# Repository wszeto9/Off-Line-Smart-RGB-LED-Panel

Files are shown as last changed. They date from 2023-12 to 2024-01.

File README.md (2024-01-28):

# Off-Line Smart RGB LED Panel
A constant current driver made to to drive 100W RGB COB LEDs straight from mains power

[Interactive BOM](https://htmlpreview.github.io/?https://github.com/wszeto9/Off-Line-Smart-RGBCCT-LED-Panel/blob/main/ibom.html)

## Testing and Validation

This is probably the most complicated board I've made so far! This isn't because it has more circuits or anything, but rather because it's powered off AC mains. I can't just plug it in and hope that it works. There's an insignificant chance it doesn't, and who knows what will happen to the circuit if a component doesn't work as expected. It goes without saying, don't try this at home! It's taken me years to feel okay designing a system like this, and it isn't a project to build on a whim. Nevertheless, let's look into the bringup process. 

### 24VDC Buck

One of the easiest things to test is the 24V Buck converter. Solder it up, and stick +50VDC (0.1A max) between +HV and -HV. It's safe enough for me to feel comfortable testing it alone. Flip the power switch, and the conviniently placed LED indicator turns on, suggesting that the power rail works. Sticking a multimeter on the power rail shows... ***25.5V***? Interesting. I wonder if it's because there's no load on it. I'll have to look at it again once I get some load put together. For now, it's fine. The 3.3V regulator doesn't care as long as it's below 28V, and the LED drivers are okay with up to a few hundred volts. The LNK3206 IC the design is based on also has a soft-start feature, and that seems to work great. Rise time seems to be ~ 16 ms, no overshoots or anything. Cool! 

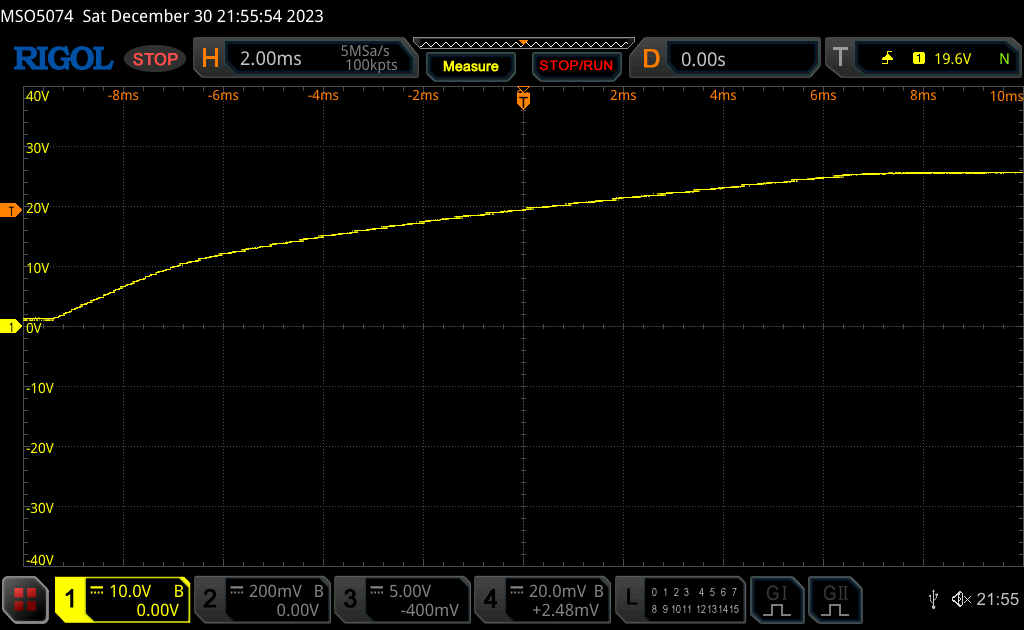
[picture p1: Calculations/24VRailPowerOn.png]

*Soft-start of 24V rail. +HV = 60V DC*

### Bulk Capacitor Discharge Testing

Before I even consider plugging this into the wall, I need to ensure that the bulk capacitors are able to drain in a reasonable time after being unplugged. Bulk capacitors without bleed resistors are one of the scariest things to see. There's no telling whether it's at 400V or 0V simply by looking, and one slip up during measurement would be very dangerous. In this test, I'll inject +60VDC between +HV and -HV. Then I'll measure the voltage across C2. +60VDC is high enough that I can extrapolate discharge rate to +169VDC, while also being low enough that I'd be okay starting with it. 

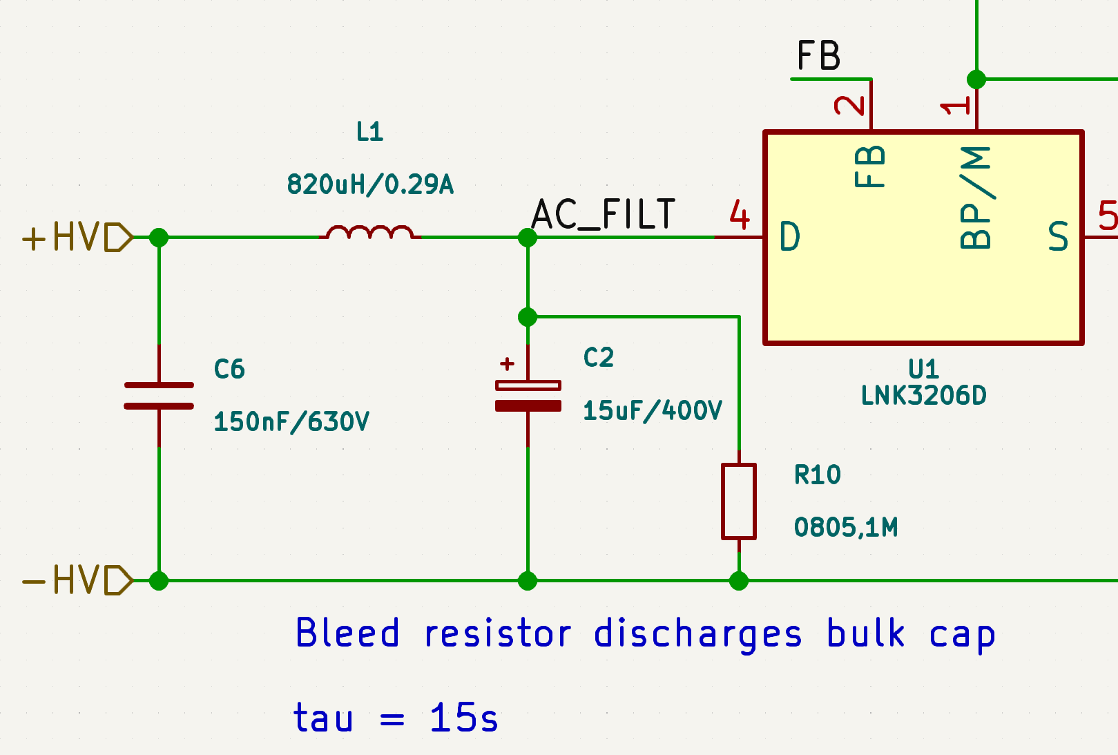
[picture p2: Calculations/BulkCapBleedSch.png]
Bulk Capacitor Discharge Schematic

*Schematic of Bleed Circuit, Rev A02*

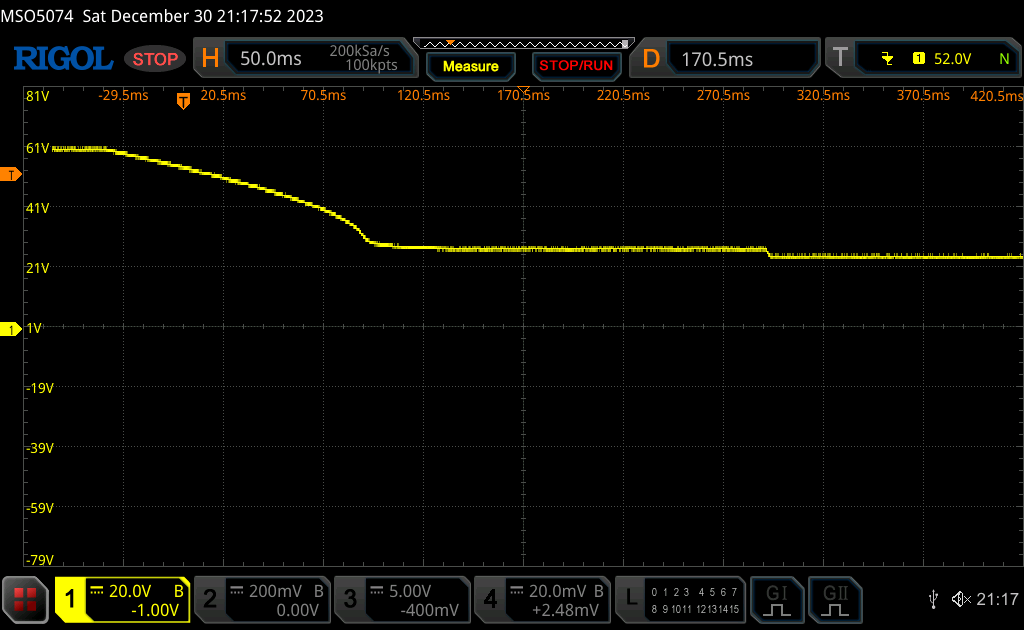
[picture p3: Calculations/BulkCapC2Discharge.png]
Bulk Capacitor Discharge Schematic

*Voltage across C2 after +HV is turned off. Initial discharge rate seems to be approximately 20V/100ms, or 200V/s*

Looking at the discharge rate, it seems to be much higher than expected. The calculations show a 15 second time-constant from a 1M/15.5uF system. The measured time constant is much less than 1 second. This might be since the Buck converter is attached to the circuit, which has ~ 10k of load at 24V. Assuming 100% efficiency, that would equate to ~ 24k of load at 60V, and it's also a psudo-constant power load since the buck converter wants to keep the output at 24V. With a 24k / 15.5uF system, that gets a tau of 0.36 seconds, fairly close to what's observed. The constant power load also explain why the discharge rate seems to accelerate when the capacitor voltage gets closer to 25V.

### LED Current Regulation Testing, 62VDC

Once the +24V Buck was validated, the LED driver can be validated next. +HV is set to +62VDC since that's the highest 2x 30V power supplies can deliver. A 12V LED strip was used to be a load for testing. The LED strip drew 1A at 12V for a total of 12W of power draw. The power supplies were set to 0.2A max in order to ensure that in the event that the LED driver did not work, the LEDs would not be supplied past their rated power. 

When powered up, the LEDs do not turn on until a 3.3V PWM signal was applied. Once the PWM signal was applied, the LED strip did not shine at full brightness. This is likely because the LD configuration only allows for full power draw when +HV is at 169VDC. Since +HV is +62VDC, the LEDs are likely at roughly 1/3 the maximum current draw. 

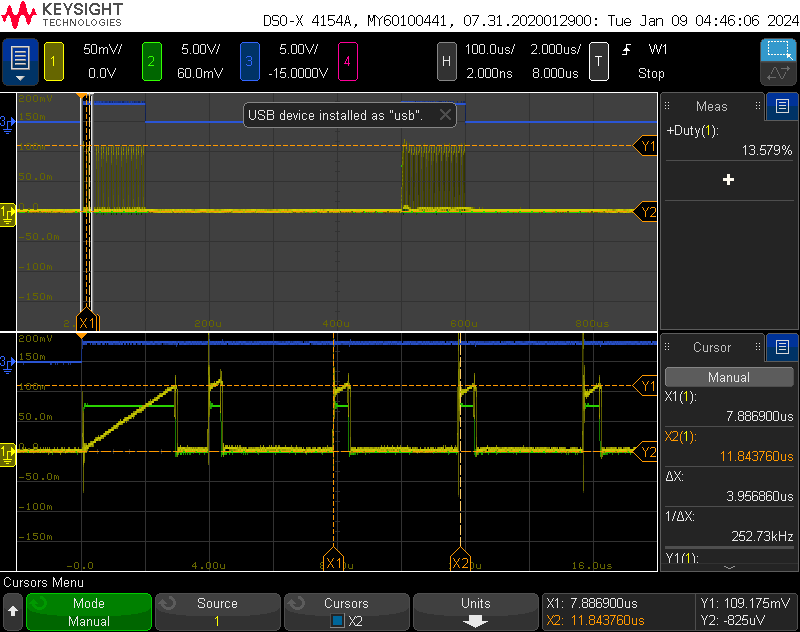
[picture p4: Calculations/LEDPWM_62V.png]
LED PWM testing, 62VDC +HV, 20% PWM


Scope capture of LED current regulation, Rev A02. +HV = 62V, PWM = 20% Duty Cycle, 3.3V logic. Blue = PWM, Green = GATE, Yellow = Isense. 0.1V on Isense is 0.33A.

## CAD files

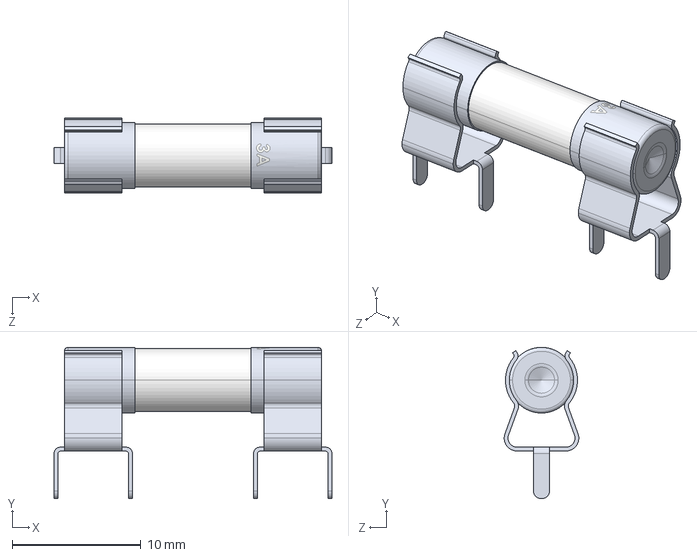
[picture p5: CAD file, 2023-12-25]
3D Models/Fuse Holder.STEP
21.6 x 11.8 x 5.80 mm
Fuse Clip x 2
3A Fuse

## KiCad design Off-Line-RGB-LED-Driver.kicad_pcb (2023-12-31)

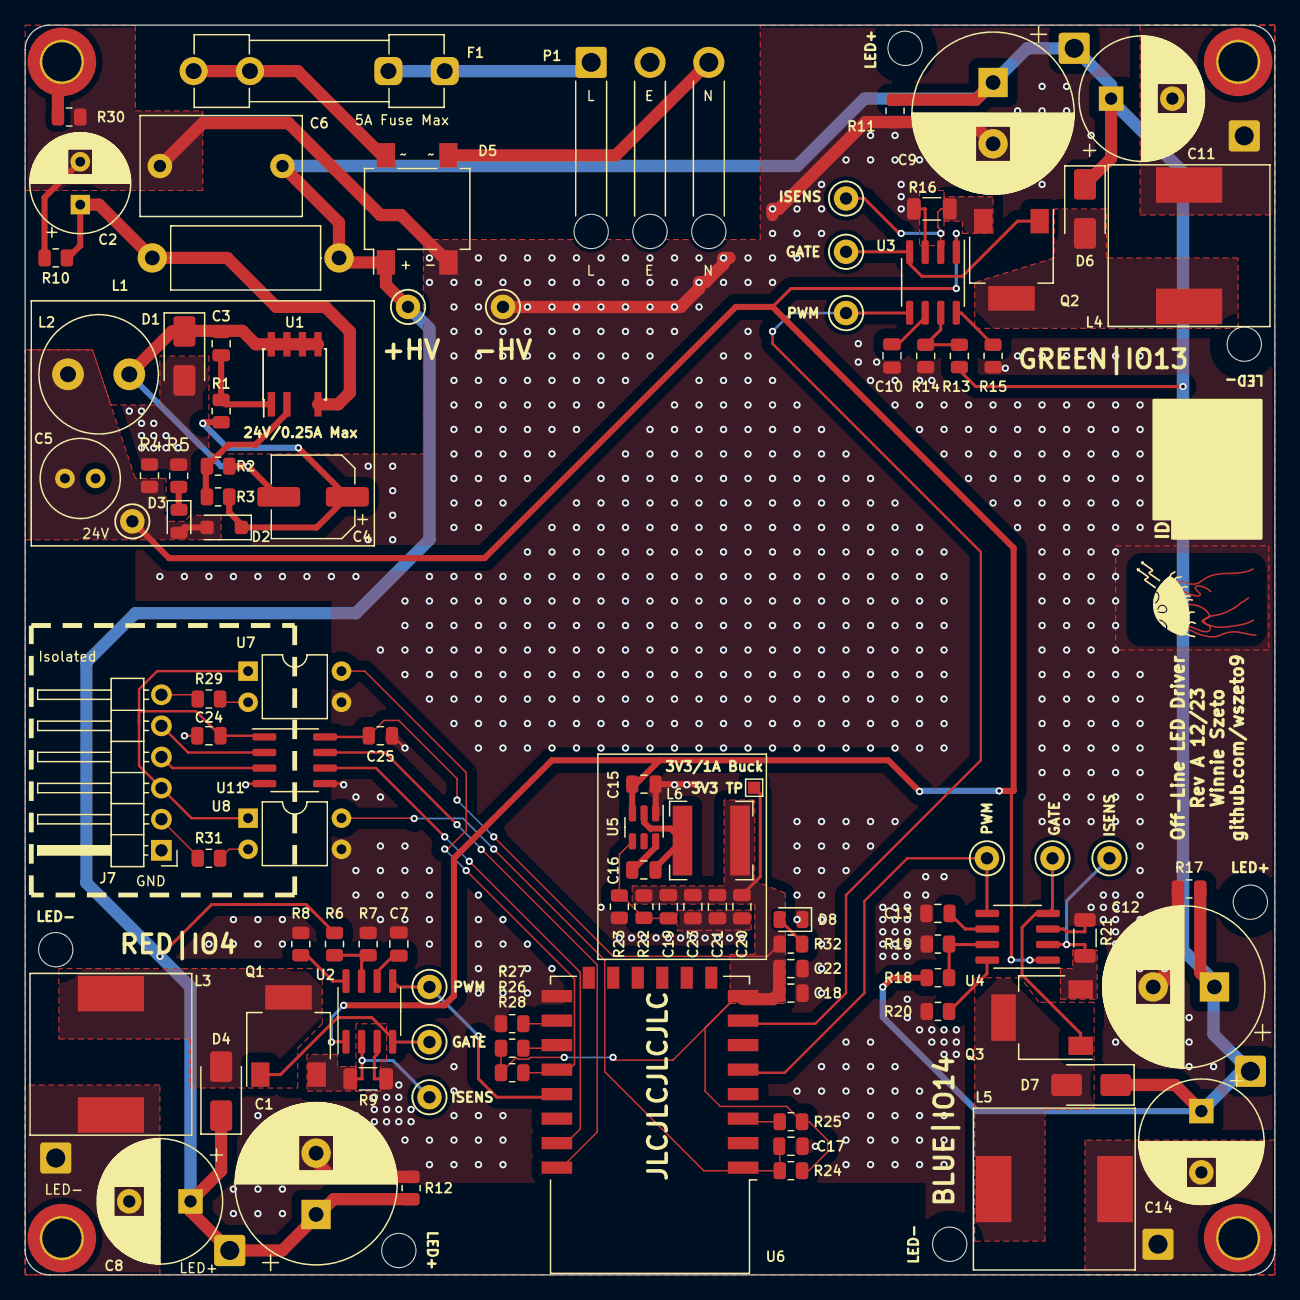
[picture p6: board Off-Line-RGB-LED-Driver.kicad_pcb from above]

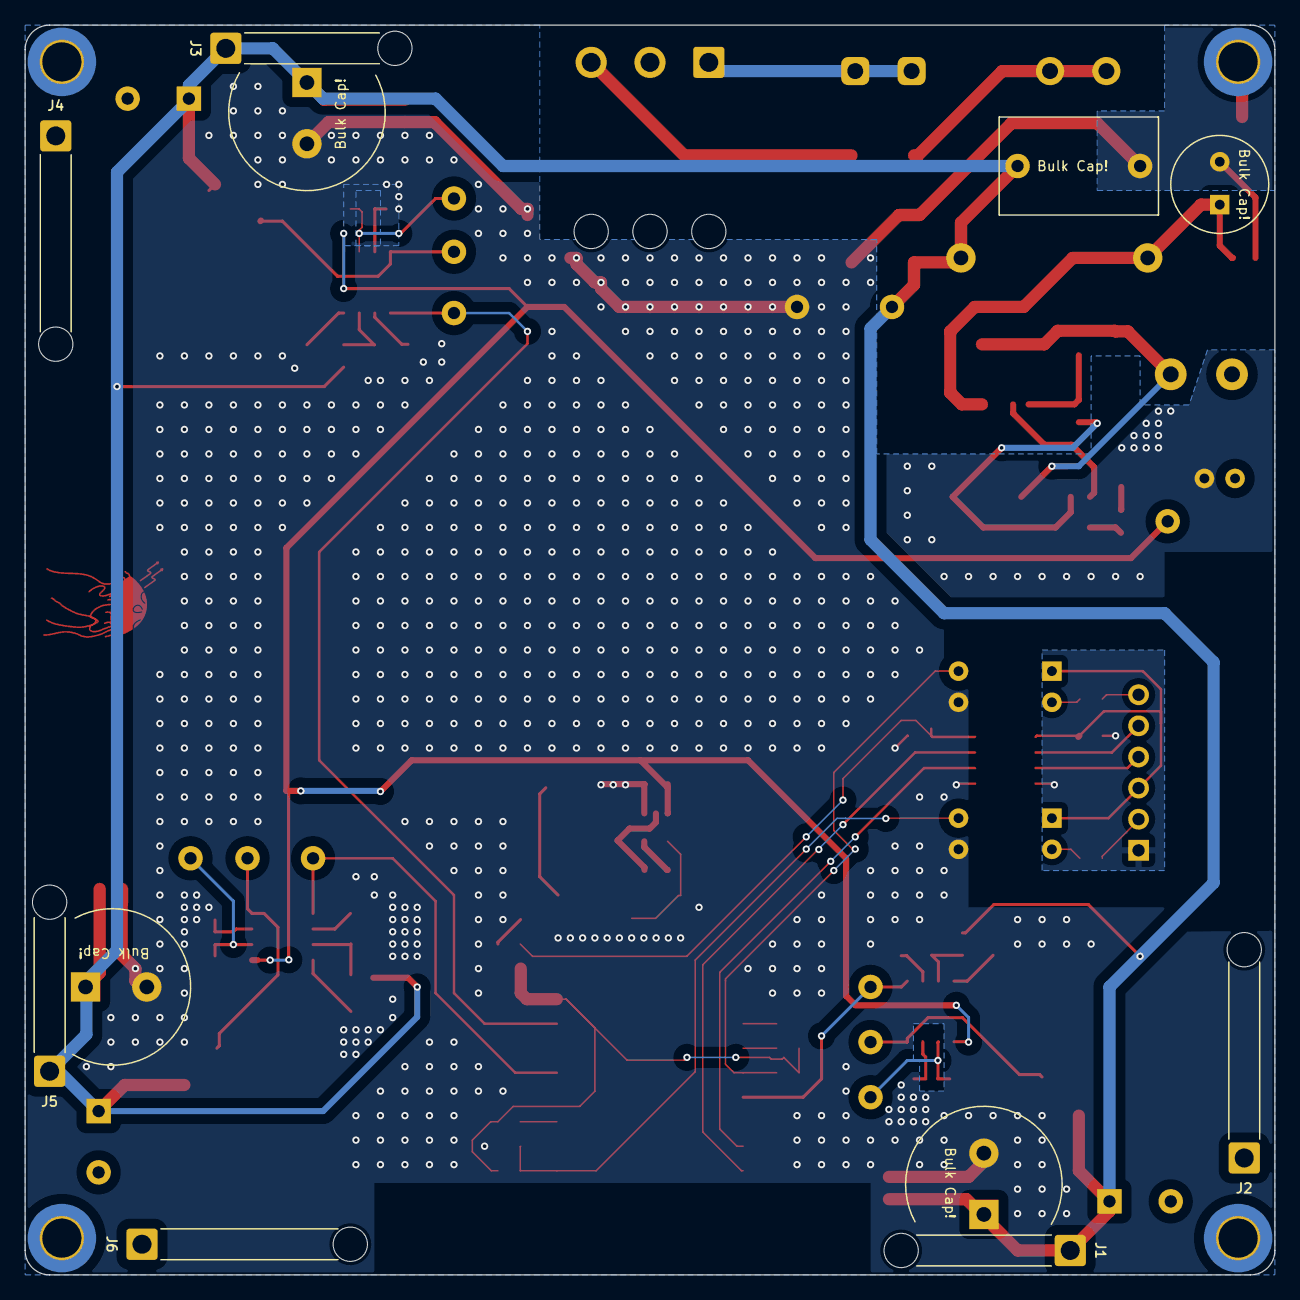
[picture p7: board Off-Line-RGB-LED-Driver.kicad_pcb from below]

Board: 2 copper layers, 102.0 x 102.0 mm, 110 parts (6 on the bottom side), 57 nets.

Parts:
C1, C9, C12: 56uF/450V; CP_Radial_D13.0mm_P5.00mm
C2: 15uF/400V; CP_Radial_D8.0mm_P3.50mm
C3, C16, C24, C25: 0805,100nF,50V,X7R; C_0805_2012Metric
C4: 10uF/35V; CP_Elec_6.3x5.4
C5: 100uF/35V; C_Radial_D6.3mm_H11.0mm_P2.50mm
C6: 150nF/630V; C_Rect_L13.0mm_W8.0mm_P10.00mm_FKS3_FKP3_MKS4
C7, C10, C13, C17, C18: 0805,1uF,50V,X7R; C_0805_2012Metric
C8, C11, C14: 220uF/50V; CP_Radial_D10.0mm_P5.00mm
C15: 0805,10uF,50V,X5R; C_0805_2012Metric
C19: 0805,47pF,50V,C0G; C_0805_2012Metric
C20, C21, C23: 0805,47uF,6.3V,X5R; C_0805_2012Metric
C22: 0805,10nF,50V,X7R; C_0805_2012Metric
D1, D4, D6, D7: ES2G; D_SMA
D2: RS1MWF-7; D_SOD-123F
D3, D8: LED 0805 W; LED_0805_2012Metric
D5: DB207S; Diode_Bridge_Vishay_DFSFlat
F1: 5A/250V; Fuseholder_Clip-5x20mm_Littelfuse_100_Inline_P20.50x4.60mm_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
H1, H2, H3, H4: MountingHole_Pad; MountingHole_3.2mm_M3_DIN965_Pad_TopBottom
J1, J3, J5: SolderWire_LED+; SolderWire-0.75sqmm_1x01_D1.25mm_OD2.3mm_Relief
J2, J4, J6: SolderWire_LED-; SolderWire-0.75sqmm_1x01_D1.25mm_OD2.3mm_Relief_longer
J7: Conn_01x06_Pin; PinHeader_1x06_P2.54mm_Horizontal
L1: 820uH/0.29A; L_Axial_L12.0mm_D5.0mm_P15.24mm_Horizontal_Fastron_MISC
L2: 1mH/0.3A; L_Radial_D9.5mm_P5.00mm_Fastron_07HVP
L3, L4, L5: 470uH/1.5A; L_Neosid_SM-NE127
L6: 33uH/1.5A; L_Bourns-SRN6028
LOGO##1: Logo
P1: Conn_WallPlug_Earth; SolderWire-0.75sqmm_1x03_P4.8mm_D1.25mm_OD2.3mm_Relief
Q1, Q2, Q3: IPN70R1K4P7S; SOT-223-3_TabPin2
R1: 0805,36k; R_0805_2012Metric
R2: 0805,2k; R_0805_2012Metric
R3, R23: 0805,22k; R_0805_2012Metric
R4, R24, R25, R26, R27, R28: 0805,10k; R_0805_2012Metric
R5, R6, R11, R12, R13, R17, R18: 0805,510k; R_0805_2012Metric
R7, R14, R19: 0805,750; R_0805_2012Metric
R8, R15, R20: 0805,75k; R_0805_2012Metric
R9, R16, R21: 1206,0.3; R_1206_3216Metric
R10, R30: 0805,1M; R_0805_2012Metric
R22: 0805,100k; R_0805_2012Metric
R29, R31: 0805,330; R_0805_2012Metric
R32: 0805,1k; R_0805_2012Metric
TP1: 5000 (Red); TestPoint_Keystone_5000-5004_Miniature
TP2, TP6, TP9: 5003 (Orange); TestPoint_Keystone_5000-5004_Miniature
TP3, TP7, TP10: 5119 (Purple); TestPoint_Keystone_5000-5004_Miniature
TP4, TP5, TP8: 5117 (Blue); TestPoint_Keystone_5000-5004_Miniature
TP11: 5001 (Black); TestPoint_Keystone_5000-5004_Miniature
TP12: 5002 (White); TestPoint_Keystone_5000-5004_Miniature
TP13: TestPoint_Pad_1.0x1.0mm
U1: LNK3206D; PowerIntegrations_SO-8C
U2, U3, U4: AL9910-5S-13; SOIC-8_3.9x4.9mm_P1.27mm
U5: TPS54202DDC; SOT-23-6
U6: ESP-12F; ESP-12E
U7, U8: PC817; DIP-4_W7.62mm
U11: ISO7321C; SOIC-8_3.9x4.9mm_P1.27mm

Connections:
+3.3V: C18.1, C19.1, C20.1, C21.1, C22.1, C23.1, C25.2, L6.2, R22.1, R24.1, R25.1, R26.1, R28.1, R32.1, TP13.1, U6.8 (VCC), U11.8 (VCC2)
+5VA: C24.2, J7.3, U7.1, U8.1, U11.1 (VCC1)
+24V: C5.1, C15.1, D2.2 (A), D3.2 (A), L2.2, R4.1, TP1.1, U2.1 (VIN), U3.1 (VIN), U4.1 (VIN), U5.3 (VIN)
/AC_L: F1.1, P1.1 (AC_P)
/AC_L_Fused: D5.4, F1.2
/AC_N: D5.3, P1.3 (AC_N)
/AC_Rectified_+: C1.1, C6.1, C8.1, C9.1, C11.1, C12.1, C14.1, D4.1 (K), D5.1 (+), D6.1 (K), D7.1 (K), J1.1, J3.1, J5.1, L1.1, R6.1, R11.1, R12.1, R13.1, R17.1, R18.1, TP11.1
/BSig: TP8.1, U4.5 (PWM_D), U6.5 (GPIO14)
/ESP8266/DTR: J7.6, R29.1
/ESP8266/GPIO0: R28.2, U6.18 (GPIO0), U7.4
/ESP8266/RST: C17.1, R24.2, U6.1 (~RST), U8.4
/ESP8266/RTS: J7.2, R31.1
/ESP8266/RXD0: U6.21 (GPIO3/RXD), U11.6 (OUTB)
/ESP8266/RXD_ESP: J7.4, U11.3 (INB)
/ESP8266/TXD0: U6.22 (GPIO1/TXD), U11.7 (INA)
/ESP8266/TXD_ESP: J7.5, U11.2 (OUTA)
/GSig: TP5.1, U3.5 (PWM_D), U6.7 (GPIO13)
/Non-Isolated-24V-Switcher/AC_FILT: C2.1, L1.2, R10.1, U1.4 (D)
/Non-Isolated-24V-Switcher/FB: R2.1, R3.1, U1.2 (FB)
/Non-Isolated-24V-Switcher/SwitchNode: C3.2, C4.2, D1.1 (K), L2.1, R2.2, U1.5 (S), U1.6 (S), U1.7 (S), U1.8 (S)
/PFCLEDBuck1/LD: R13.2, R14.1, U3.7 (LD)
/PFCLEDBuck1/LED-: C11.2, J4.1, L4.2
/PFCLEDBuck1/LED_SW_NODE: D6.2 (A), L4.1, Q2.2 (D)
/PFCLEDBuck2/LD: R18.2, R19.1, U4.7 (LD)
/PFCLEDBuck2/LED-: C14.2, J6.1, L5.2
/PFCLEDBuck2/LED_SW_NODE: D7.2 (A), L5.1, Q3.2 (D)
/PFCLEDBuck/LD: R6.2, R7.1, U2.7 (LD)
/PFCLEDBuck/LED-: C8.2, J2.1, L3.2
/PFCLEDBuck/LED_SW_NODE: D4.2 (A), L3.1, Q1.2 (D)
/RSig: TP4.1, U2.5 (PWM_D), U6.19 (GPIO4)
GND: C1.2, C2.2, C5.2, C6.2, C7.1, C9.2, C10.1, C12.2, C13.1, C15.2, C17.2, C18.2, C20.2, C21.2, C22.2, C23.2, C25.1, D1.2 (A), D5.2 (-), D8.1 (K), R4.2, R5.2, R7.2, R8.2, R9.2, R10.2, R11.2, R12.2, R14.2, R15.2, R16.2, R17.2, R19.2, R20.2, R21.2, R23.2, R27.2, R30.2, TP12.1, U2.3 (GND), U3.3 (GND), U4.3 (GND), U5.1 (GND), U6.15 (GND), U7.3, U8.3, U11.5 (GND2)
GNDS: C24.1, J7.1, U11.4 (GND1)
unnamed: C4.1, D2.1 (K), R1.2, R3.2
unnamed: D3.1 (K), R5.1
unnamed: D8.2 (A), R32.2
unnamed: H1.1, R30.1
unnamed: Q1.1 (G), TP2.1, U2.4 (GATE)
unnamed: Q1.3 (S), R9.1, TP3.1, U2.2 (CS)
unnamed: Q2.1 (G), TP6.1, U3.4 (GATE)
unnamed: Q2.3 (S), R16.1, TP7.1, U3.2 (CS)
unnamed: Q3.1 (G), TP9.1, U4.4 (GATE)
unnamed: Q3.3 (S), R21.1, TP10.1, U4.2 (CS)
unnamed: R29.2, U7.2
unnamed: R31.2, U8.2
unnamed: C3.1, R1.1, U1.1 (BP/M)
unnamed: R8.1, U2.8 (ROSC)
unnamed: C7.2, U2.6 (VDD)
unnamed: R15.1, U3.8 (ROSC)
unnamed: C10.2, U3.6 (VDD)
unnamed: R20.1, U4.8 (ROSC)
unnamed: C13.2, U4.6 (VDD)
unnamed: C16.1, U5.6 (BOOT)
unnamed: C19.2, R22.2, R23.1, U5.4 (FB)
unnamed: C16.2, L6.1, U5.2 (SW)
unnamed: R25.2, U6.3 (EN)
unnamed: R26.2, U6.17 (GPIO2)
unnamed: R27.1, U6.16 (GPIO15)

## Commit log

2023-12-25 Laid out Rev A
    [3.3VOutBuck.kicad_sch, AL9910.kicad_sch, Fuse Holder.STEP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]
2023-12-31 [A02] Edited R4, R5
    R4 20k -> 10k since nothing else uses 20k
    R5 10k -> 510k to reduce D3 LED brightness
    [3.3VOutBuck.kicad_sch, AL9910.kicad_sch, LNK3207.kicad_sch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]
2023-12-31 Added documentation for 24V buck validation
2023-12-31 accidentily made thermal reliefs, reverting them
    [Off-Line-RGB-LED-Driver.kicad_pcb]
2024-01-28 added current regulation test
